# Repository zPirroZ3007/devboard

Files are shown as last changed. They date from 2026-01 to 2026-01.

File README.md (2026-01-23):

# STM32 Devboard

This is my first serious PCB designed for manufacturing.  
It's a microcontroller development board based on the **STM32F411CEU6**.

---

## 🎯 Project Goals

- [x] Learn basics of schematic organization
- [x] Learn basics of PCB routing and component placement
- [x] Get familiar with PCBWay and Chinese manufacturing
- [x] Achieve plug-and-play support in Arduino IDE via USB-C
- [x] Small form factor, **breadboard-friendly**

---

Youtube Video (https://youtu.be/whQsK2HDIRk)

## 📷 Project Media

<p align="center">
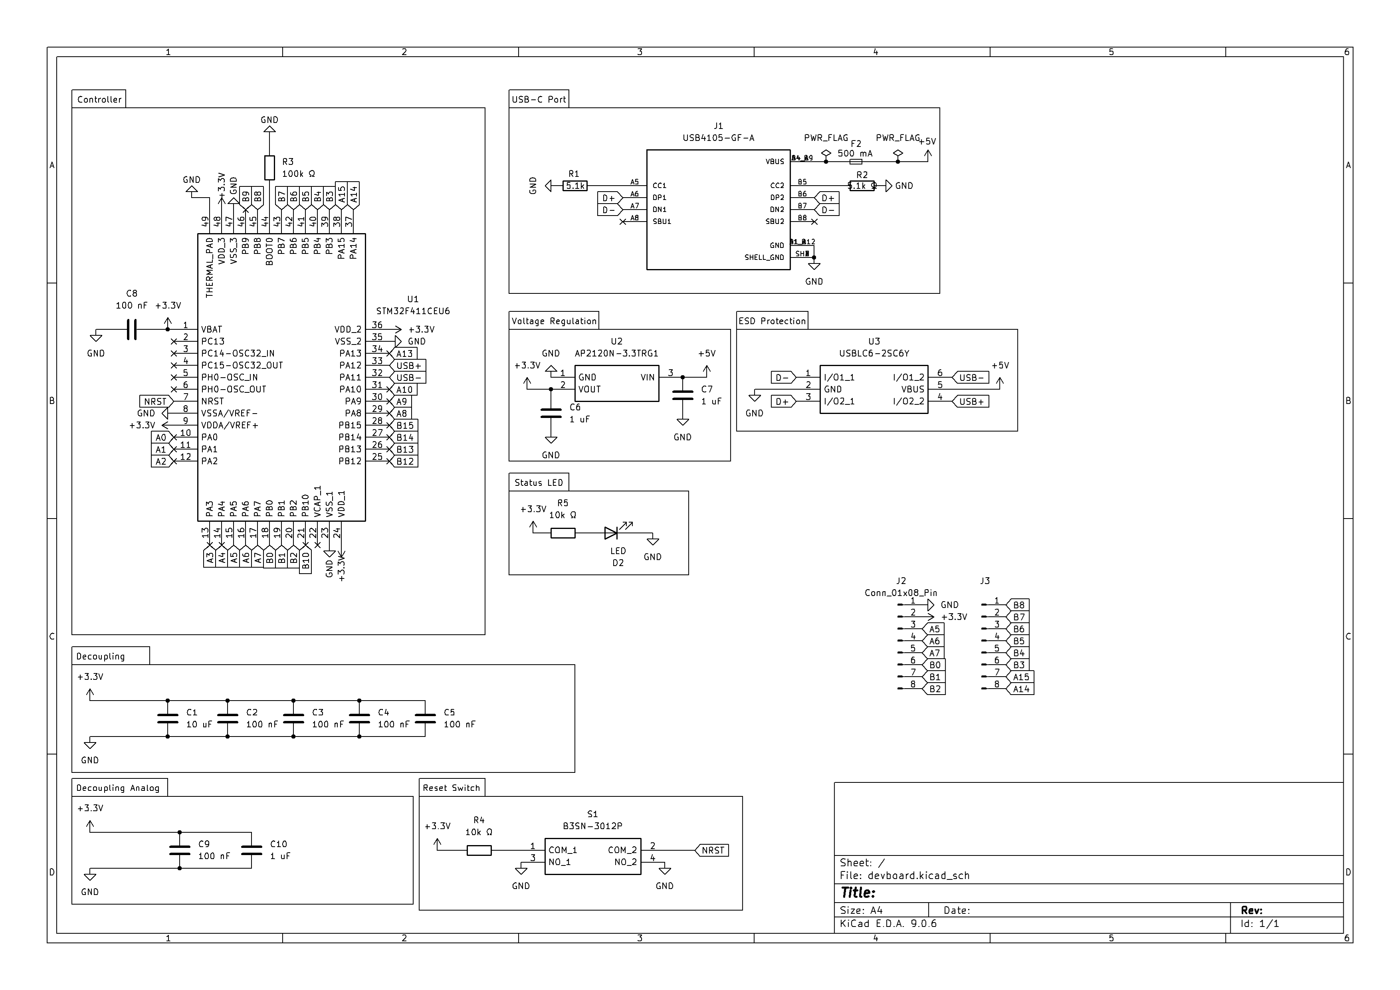
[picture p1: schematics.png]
  
  <br/><br/>
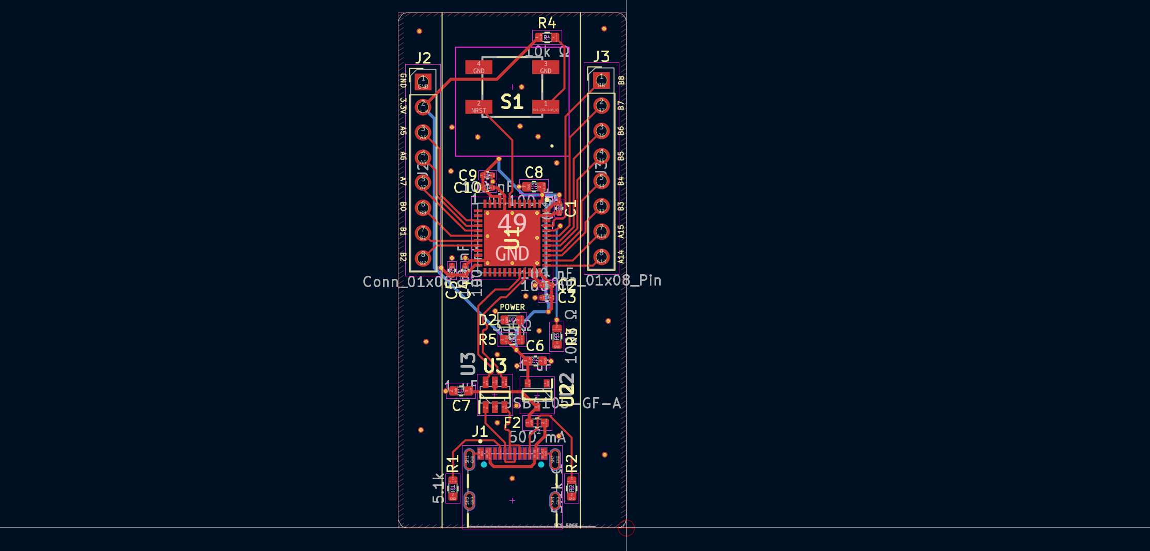
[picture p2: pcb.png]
  
  <br/><br/>
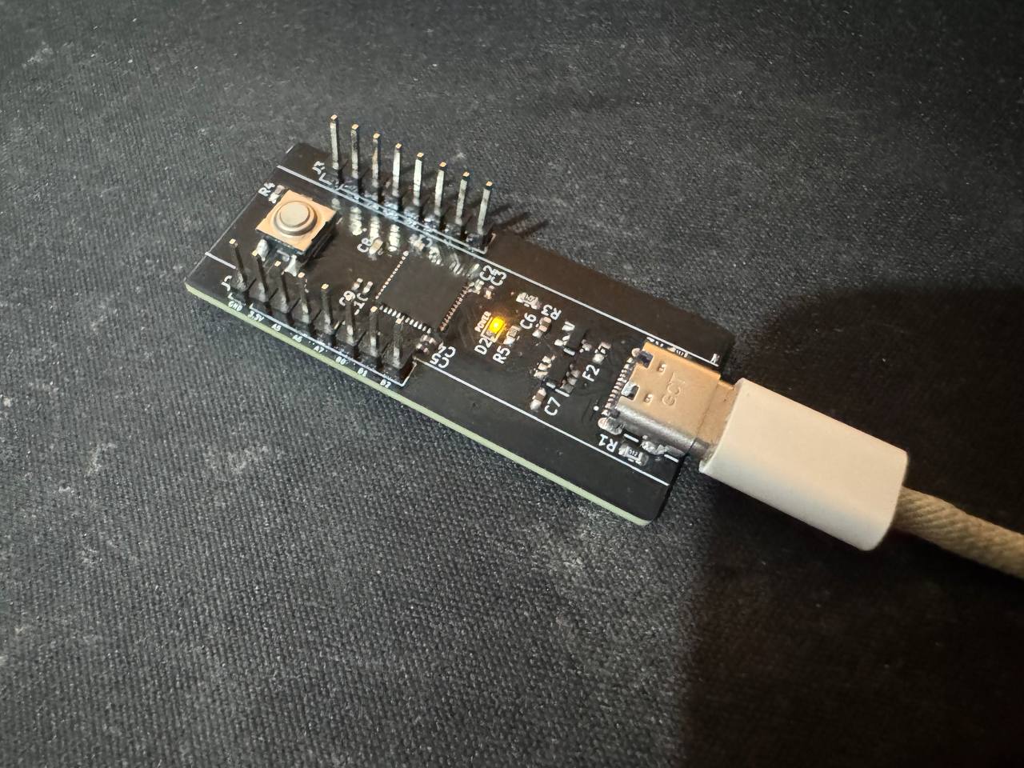
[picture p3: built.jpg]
  
</p>

---

## 🧩 MCU Specs (STM32F411CEU6)

- ARM Cortex-M4 @ 100 MHz
- 512 KB Flash, 128 KB SRAM
- USB OTG
- SPI / I2C / UART
- ADC / TIM / DMA

---

## 🛠 Toolchain

- **ECAD:** KiCad
- **Manufacturing:** PCBWay
- **Firmware:** Arduino IDE / STM32 Core
- **Debugging:** SWD

---

## 📦 Status

Power-up tests were successful: power rails are within expected ranges and no shorts were observed. Next step is flashing the initial firmware via ST-Link.

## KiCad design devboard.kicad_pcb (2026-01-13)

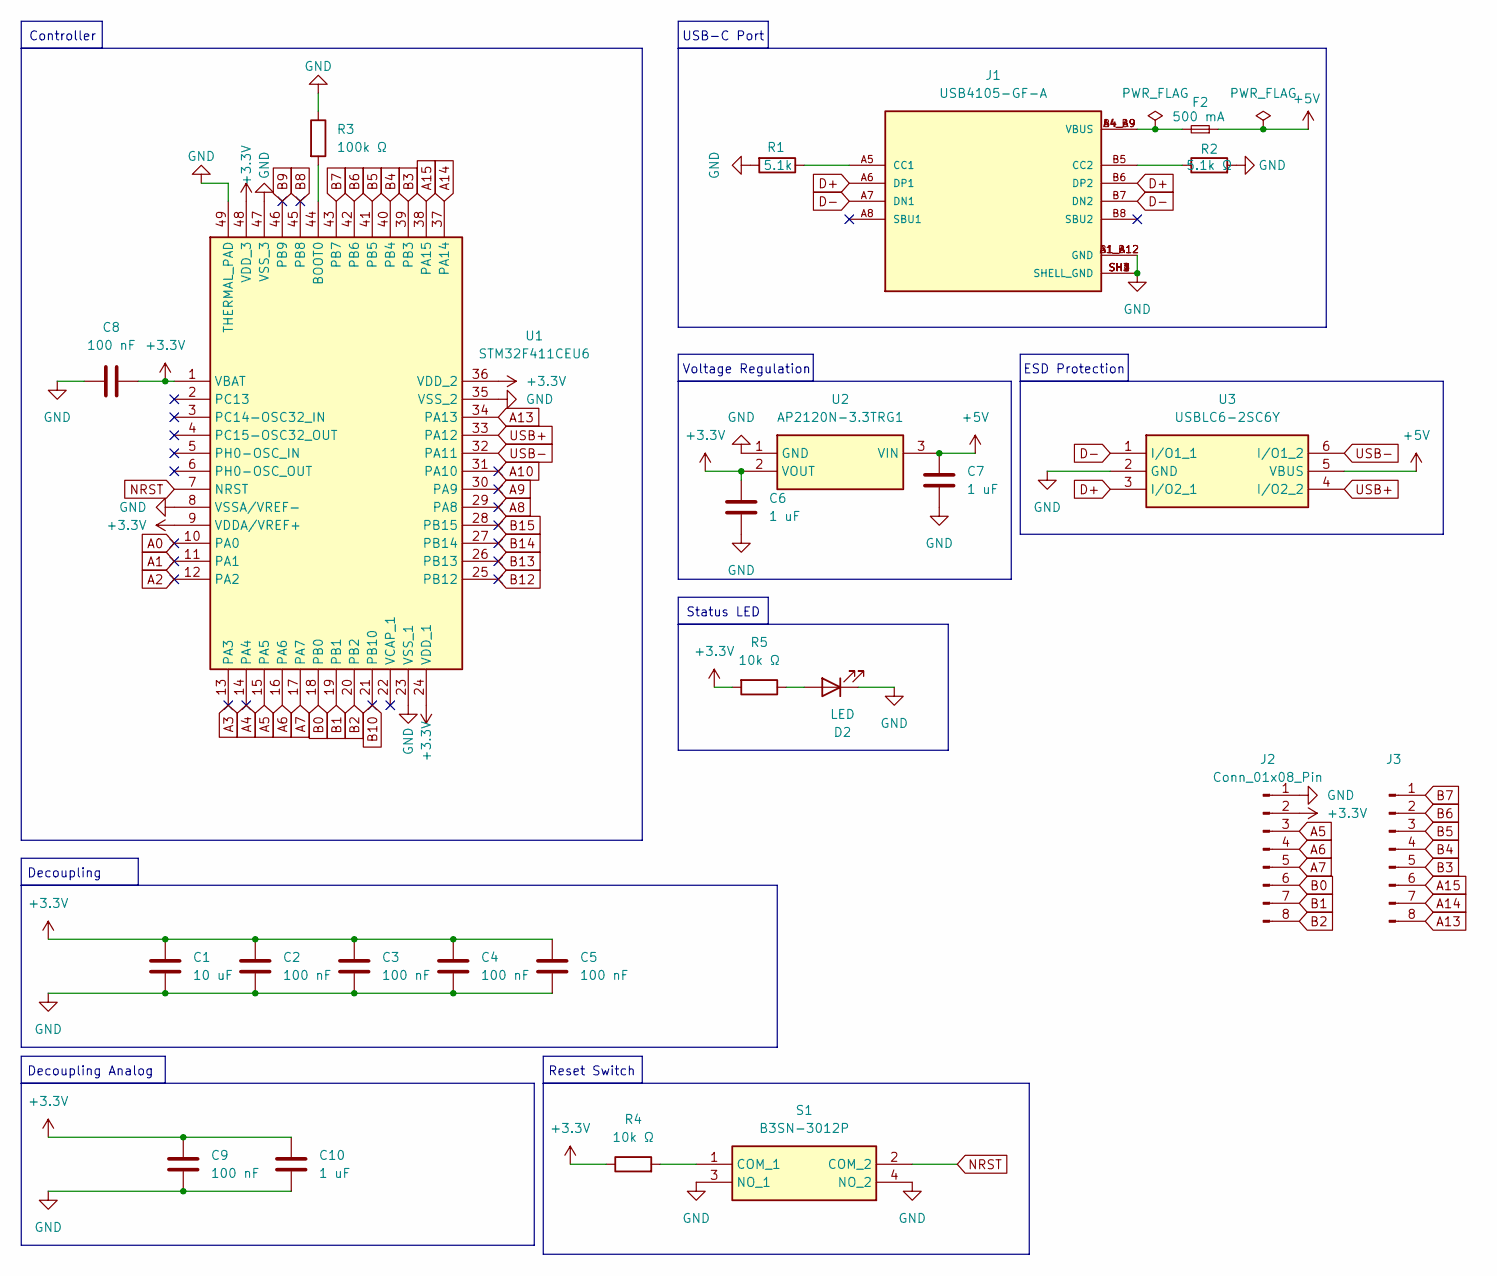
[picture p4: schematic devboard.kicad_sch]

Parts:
C1: 10 uF; C_0402_1005Metric
C2, C3, C4, C5, C9: 100 nF; C_0402_1005Metric
C6, C7: 1 uF; C_0603_1608Metric
C8: 100 nF; C_0603_1608Metric
C10: 1 uF; C_0402_1005Metric
D2: LED; LED_0603_1608Metric
F2: 500 mA; Fuse_0603_1608Metric
J1: USB4105-GF-A; GCT_USB4105-GF-A; PARTREV B4
J2, J3: Conn_01x08_Pin; PinHeader_1x08_P2.54mm_Vertical
R1: 5.1k; R_0603_1608Metric
R2: 5.1k Ω; R_0603_1608Metric
R3: 100k Ω; R_0603_1608Metric
R4, R5: 10k Ω; R_0603_1608Metric
S1: B3SN-3012P; B3SN3012P; Mouser Part Number 653-B3SN-3012P
U1: STM32F411CEU6; QFN50P700X700X60-49N-D; Mouser Part Number 511-STM32F411CEU6
U2: AP2120N-3.3TRG1; SOT96P240X105-3N; Mouser Part Number 621-AP2120N-3.3TRG1
U3: USBLC6-2SC6Y; SOT95P280X145-6N; Mouser Part Number 511-USBLC6-2SC6Y

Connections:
+3.3V: C1.1, C2.1, C3.1, C4.1, C5.1, C6.1, C8.2, C9.1, C10.1, J2.2, R4.1, R5.2, U1.1 (VBAT), U1.9 (VDDA/VREF+), U1.24 (VDD_1), U1.36 (VDD_2), U1.48 (VDD_3), U2.2 (VOUT)
+5V: C7.1, F2.1, U2.3 (VIN), U3.5 (VBUS)
A0: U1.10 (PA0)
A1: U1.11 (PA1)
A2: U1.12 (PA2)
A3: U1.13 (PA3)
A4: U1.14 (PA4)
A5: J2.3, U1.15 (PA5)
A6: J2.4, U1.16 (PA6)
A7: J2.5, U1.17 (PA7)
A8: U1.29 (PA8)
A9: U1.30 (PA9)
A10: U1.31 (PA10)
A13: J3.8, U1.34 (PA13)
A14: J3.7, U1.37 (PA14)
A15: J3.6, U1.38 (PA15)
B0: J2.6, U1.18 (PB0)
B1: J2.7, U1.19 (PB1)
B2: J2.8, U1.20 (PB2)
B3: J3.5, U1.39 (PB3)
B4: J3.4, U1.40 (PB4)
B5: J3.3, U1.41 (PB5)
B6: J3.2, U1.42 (PB6)
B7: J3.1, U1.43 (PB7)
B8: U1.45 (PB8)
B9: U1.46 (PB9)
B10: U1.21 (PB10)
B12: U1.25 (PB12)
B13: U1.26 (PB13)
B14: U1.27 (PB14)
B15: U1.28 (PB15)
D+: J1.A6 (DP1), J1.B6 (DP2), U3.3 (I/O2_1)
D-: J1.A7 (DN1), J1.B7 (DN2), U3.1 (I/O1_1)
GND: C1.2, C2.2, C3.2, C4.2, C5.2, C6.2, C7.2, C8.1, C9.2, C10.2, D2.1 (K), J1.A1_B12 (GND), J1.B1_A12 (GND), J1.SH1 (SHELL_GND), J1.SH2 (SHELL_GND), J1.SH3 (SHELL_GND), J1.SH4 (SHELL_GND), J2.1, R1.2, R2.2, R3.1, S1.3 (NO_1), S1.4 (NO_2), U1.8 (VSSA/VREF-), U1.23 (VSS_1), U1.35 (VSS_2), U1.47 (VSS_3), U1.49 (THERMAL_PAD), U2.1 (GND), U3.2 (GND)
NRST: S1.2 (COM_2), U1.7 (NRST)
unnamed: D2.2 (A), R5.1
unnamed: F2.2, J1.A4_B9 (VBUS), J1.B4_A9 (VBUS)
unnamed: J1.A5 (CC1), R1.1
unnamed: J1.B5 (CC2), R2.1
unnamed: R4.2, S1.1 (COM_1)
unnamed: R3.2, U1.44 (BOOT0)
USB+: U1.33 (PA12), U3.4 (I/O2_2)
USB-: U1.32 (PA11), U3.6 (I/O1_2)

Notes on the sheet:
USB-C Port
Decoupling
Status LED
ESD Protection
Decoupling Analog
Controller
Reset Switch
Voltage Regulation

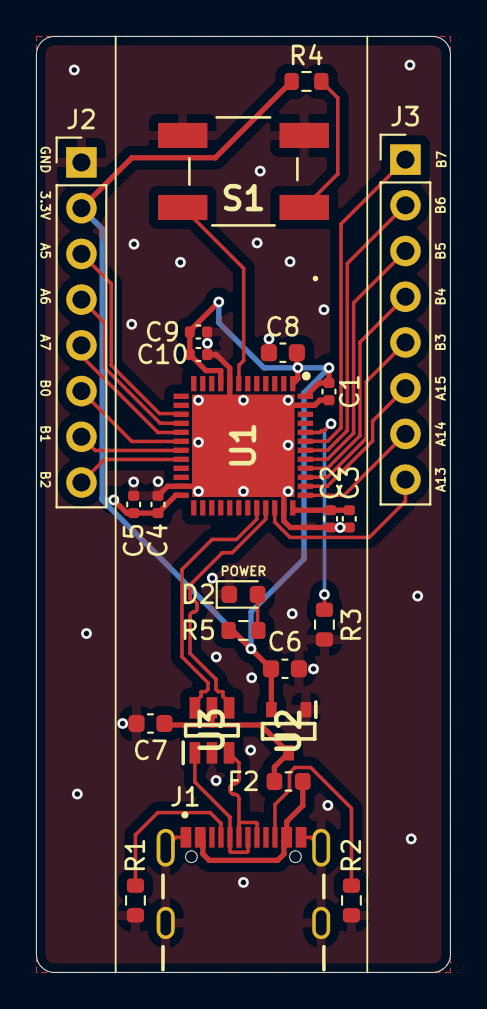
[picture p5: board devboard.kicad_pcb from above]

Board: 2 copper layers, 23.0 x 52.0 mm, 24 parts (0 on the bottom side), 28 nets.

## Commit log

2025-12-16 Total board refactoring: - Full board routing - Ready for manufacturing - Schematic fixing ad improvements
    [devboard.kicad_pcb, devboard.kicad_sch]
2025-12-16 Fixed all DRC errors
    [devboard.kicad_pcb]
2025-12-16 Default clearance fixed 0.15mm
2025-12-16 Fixed serigraphy
    [devboard.kicad_pcb]
2025-12-16 Ground connections fixes
    [devboard.kicad_pcb]
2025-12-16 Fixed ALL DRC and unconnected errors
    [devboard.kicad_pcb]
2025-12-17 Fix VBAT
    [devboard.kicad_pcb, devboard.kicad_sch]
2026-01-11 Increase PWR LED resistence value + better silkscreen placement
    [devboard.kicad_pcb, devboard.kicad_sch]
2026-01-13 Expose A13 to work with ST-Link
    [devboard.kicad_pcb, devboard.kicad_sch]
